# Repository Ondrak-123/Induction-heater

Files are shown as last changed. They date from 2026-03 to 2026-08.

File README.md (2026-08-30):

Macondo link: https://macondo.hackclub.com/projects/6495
# Induction heater
- **This project is an Induction heater based on oscillation (ZVS-Zero Voltage Switching).**
- **The journal can be found at https://stasis.hackclub.com/dashboard/projects/cmmuu5lqf00kx01ns6pu1y2ej (project was started on Statis and now will be finished on Macondo!**
- **The journal features all guides, progress, explanations on how ZVS works and why it is the best way.**
  
**Why am I using softswitching and what is it?**

- Soft switch makes sure that the circuit is not powered instantly but after some time, when connecting an aligator clip or other power source you connect and disconnect the power supply multiple times which can fry the mosfets.

**Why is it called "Zero Voltage Switching"?**

- If one side of the circuit reaches zero volts, it triggers one MOSFET to turn on, while the other stays off and this cycle continues on and on.

**Why is it so efficient?**

- It is efficient thanks to the zero voltage switching, as you can probably tell by the name the mosfets switch at zero volts, thanks to this there is not as much heat generated.

_**Pictures:**_















Created a completely new BOM!:

| I will be using a seller based in the EU. (TME.EU). to avoid new tariff for the EU. I also included AliExpress link so everyone can do this project. I will have 2 orders one from JLCPCB that costs 8.44$. second one from TME.EU. all costs calculated in the total. |  |  |  |  |  |  |  |  |  |  |  |  |  |  |  |  |  |  |  |  |  |
| --- | --- | --- | --- | --- | --- | --- | --- | --- | --- | --- | --- | --- | --- | --- | --- | --- | --- | --- | --- | --- | --- |
| Name | Symbol/TME Code: | Purpose | Link: | Quantity needed: | Total Cost (CZK): | Total cost (USD): |  |  |  |  | Link | Distributor |  |  |  |  |  |  |  |  |  |
| PCB |  | From JLCPCB | * | 1 | *0* | $8.44 |  |  |  |  | https://jlcpcb.com/ | JLCPCB |  |  |  |  |  |  |  |  |  |
| IN4007 Diode |  | For soft starter. | * | 1 | *0* | *0* |  |  |  |  | https://www.aliexpress.com/item/1005010128860199.html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 | Aliexpress |  |  |  |  |  |  |  |  |  |
| Resistor 100KR |  | For soft starter. | * | 1 | *0* | *0* |  |  |  |  | https://www.aliexpress.com/item/1005007539842999.html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 | Aliexpress |  |  |  |  |  |  |  |  |  |
| Power cable |  | For power. HIGH AWG. | * | 1 | *0* | *0* |  |  |  |  | https://www.aliexpress.com/item/1005005203646529.html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 | Aliexpress |  |  |  |  |  |  |  |  |  |
| Freewheeling diode SB1100 | SB1100-DIO | 100V 1A | https://www.tme.eu/cz/details/sb1100-dio/diody-schottky-tht/diotec-semiconductor/sb1100/ | 2 | 7.020 | *0* |  |  |  |  | https://www.aliexpress.com/item/1005007349885370.html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 | Aliexpress |  |  |  |  |  |  |  |  |  |
| Resistor 47R 5W | 5W-47R |  | https://www.tme.eu/cz/details/5w-47r/rezistory-tht/royalohm/mor05sj0470afi/ | 1 | 23.86 | *0* |  |  |  |  | https://www.aliexpress.com/item/1005007330288041.html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 | Aliexpress |  |  |  |  |  |  |  |  |  |
| Zener diode 15V 1W | 1N4744ATR |  | https://www.tme.eu/cz/details/1n4744atr/zenerovy-diody-tht/onsemi/ | 2 | 8.480 | *0* |  |  |  |  | https://www.aliexpress.com/item/1005006886308114.html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 | Aliexpress |  |  |  |  |  |  |  |  |  |
| Resistor 150R 5W | AC05-150R-5% |  | https://www.tme.eu/cz/details/ac05-150r-5%25/vykonne-rezistory/vishay/ac05000001500jac00/ | 2 | 43.86 | *0* |  |  |  |  | https://www.aliexpress.com/item/1005003645133625.html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 | Aliexpress |  |  |  |  |  |  |  |  |  |
| Thermal paste | QOLTEC-51630 | Better heat transfer. | https://www.tme.eu/cz/details/qoltec-51630/teplovodni-pasty/qoltec/51630/ | 2 | 45.02 | *0* |  |  |  |  | https://www.aliexpress.com/item/32833422141.html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 | Aliexpress |  |  |  |  |  |  |  |  |  |
| Capacitor 220uF | CE-220/16PHT-Y | For soft starter. MOQ: 20 | https://www.tme.eu/cz/details/ce-220_16pht-y/elektrolyticke-kondenzatory-tht/aishi/ewh1cm221e11ot/ | 1 | 32.74 | *0* |  |  |  |  | https://www.aliexpress.com/item/1005007322240823.html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 | Aliexpress |  |  |  |  |  |  |  |  |  |
| Capacitor 1.5uF/2uF | C4AF9BU4150A1XK | ZVS switching. | https://www.tme.eu/cz/details/c4af9bu4150a1xk/kondenzatory-foliove-tht/kemet/ | 2 | 157.16 | *0* |  |  |  |  | https://www.tme.eu/cz/details/c4af9bu4150a1xk/kondenzatory-foliove-tht/kemet/ | Aliexpress |  |  |  |  |  |  |  |  |  |
| Resistor 10KR 5W | CRL5W-10K | ZVS switching. MOQ: 10 | https://www.tme.eu/cz/details/crl5w-10k/vykonne-rezistory/sr-passives/ | 2 | 28.46 | *0* |  |  |  |  | https://www.aliexpress.com/item/1005006363058219.html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 | Aliexpress |  |  |  |  |  |  |  |  |  |
| Transistor 2N7000 | 2N7000-DIO | For soft starter. | https://www.tme.eu/cz/details/2n7000-dio/tranzistory-s-kanalem-n-tht/diotec-semiconductor/2n7000/ | 3 | 18.13 | *0* |  |  |  |  | https://www.aliexpress.com/item/1005007206189883.html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 | Aliexpress |  |  |  |  |  |  |  |  |  |
| Inductors | DPT220A5 | Inductors 220uH. | https://www.tme.eu/cz/details/dpt220a5/tlumivky/ferrocore/ | 2 | 107.3 | *0* |  |  |  |  | https://www.aliexpress.com/item/1005009049853632.html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 | Aliexpress |  |  |  |  |  |  |  |  |  |
| Heatsink | SK104-38STS | Mosfet Cooling. | https://www.tme.eu/cz/details/sk104-38sts/chladice/fischer-elektronik/ | 2 | 129.23 | *0* |  |  |  |  | https://www.aliexpress.com/item/1005002711238683.html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 | Aliexpress |  |  |  |  |  |  |  |  |  |
| Mosfet IRFB7730 | IRFB7730PBF | ZVS switching. | https://www.tme.eu/cz/details/irfb7730pbf/tranzistory-s-kanalem-n-tht/infineon-technologies/ | 2 | 159.04 | *0* |  |  |  |  | https://www.aliexpress.com/item/1005011844869795.html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 | Aliexpress |  |  |  |  |  |  |  |  |  |
| Coil |  | Few turns of solid copper wire. | * | 1 | *0* | *0* |  |  |  |  |  |  |  |  |  |  |  |  |  |  |  |
| TME Shipping |  |  | * |  | 169.41 | *0* |  |  |  |  |  |  |  |  |  |  |  |  |  |  |  |
|  |  |  |  |  | 929.71 CZK | 8.44USD |  |  |  | I will not be using these links. but I included them so you cam do this project even if you are not in EU. |  |  |  |  |  |  |  |  |  |  |  |
|  |  |  | 929.71CZK = | 44.97 USD |  |  |  |  |  |  |  |  |  |  |  |  |  |  |  |  |  |
|  |  |  |  | ´+8.44 USD |  |  |  |  |  |  |  |  |  |  |  |  |  |  |  |  |  |
|  |  |  | TOTAL: | 53.41 USD |  |  |  |  |  |  |  |  |  |  |  |  |  |  |  |  |  |
|  |  | REQUESTING AMOUNT: |  | 58 USD |  | SCREENSHOTS/CARTS BELOW!! |  |  |  |  |  |  |  |  |  |  |  |  |  |  |  |
|  |  |  |  |  |  | TME.EU |  |  |  |  |  |  |  |  |  |  |  |  |  |  | LCSC.COM |



Snímek obrazovky 2026-08-20 191143
Snímek obrazovky 2026-08-20 190943

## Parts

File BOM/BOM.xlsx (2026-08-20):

I will be using a seller based in the EU, (TME.EU), to avoid new tariff for the EU. I also included AliExpress link so everyone can do this project. I will have 2 orders one from JLCPCB that costs 8,44$, second one from TME.EU, all costs calculated in the total.
Name | Symbol/TME Code: | Purpose | Link: | Quantity needed: | Total Cost (CZK): | Total cost (USD): |  | Link | Distributor
PCB |  | From JLCPCB | * | 1 | *0* | $8.44 |  | https://jlcpcb.com/ | JLCPCB
IN4007 Diode |  | For soft starter. | * | 1 | *0* | *0* |  | https://www.aliexpress.com/item/1005010128860199.html?curPageLogUid=wIl4TFkDRmTA | Aliexpress
Resistor 100KR |  | For soft starter. | * | 1 | *0* | *0* |  | https://www.aliexpress.com/item/1005007539842999.html?curPageLogUid=Yploor7BfNi6 | Aliexpress
Power cable |  | For power, HIGH AWG. | * | 1 | *0* | *0* |  | https://www.aliexpress.com/item/1005005203646529.html?curPageLogUid=I0lyyNmGkllr | Aliexpress
Freewheeling diode SB1100 | SB1100-DIO | 100V 1A | https://www.tme.eu/cz/details/sb1100-dio/diody-schottky-tht/diotec-semiconductor/sb1100/ | 2 | 7.02 Kč | *0* |  | https://www.aliexpress.com/item/1005007349885370.html?curPageLogUid=PDHqQEwCMyGC | Aliexpress
Resistor 47R 5W | 5W-47R |  | https://www.tme.eu/cz/details/5w-47r/rezistory-tht/royalohm/mor05sj0470afi/ | 1 | 23.86 Kč | *0* |  | https://www.aliexpress.com/item/1005007330288041.html?curPageLogUid=U4fOPbpAK6XU | Aliexpress
Zener diode 15V 1W | 1N4744ATR |  | https://www.tme.eu/cz/details/1n4744atr/zenerovy-diody-tht/onsemi/ | 2 | 8.48 Kč | *0* |  | https://www.aliexpress.com/item/1005006886308114.html?curPageLogUid=5Mdrg3XuXAoh | Aliexpress
Resistor 150R 5W | AC05-150R-5% |  | https://www.tme.eu/cz/details/ac05-150r-5%25/vykonne-rezistory/vishay/ac05000001500jac00/ | 2 | 43.86 Kč | *0* |  | https://www.aliexpress.com/item/1005003645133625.html?curPageLogUid=fSkWTN76PRrU | Aliexpress
Thermal paste | QOLTEC-51630 | Better heat transfer. | https://www.tme.eu/cz/details/qoltec-51630/teplovodni-pasty/qoltec/51630/ | 2 | 45.02 Kč | *0* |  | https://www.aliexpress.com/item/32833422141.html?curPageLogUid=HXpijeaxpZ5p | Aliexpress
Capacitor 220uF | CE-220/16PHT-Y | For soft starter. MOQ: 20 | https://www.tme.eu/cz/details/ce-220_16pht-y/elektrolyticke-kondenzatory-tht/aishi/ewh1cm221e11ot/ | 1 | 32.74 Kč | *0* |  | https://www.aliexpress.com/item/1005007322240823.html?curPageLogUid=mx3EbfFRgrpO | Aliexpress
Capacitor 1,5uF/2uF | C4AF9BU4150A1XK | ZVS switching. | https://www.tme.eu/cz/details/c4af9bu4150a1xk/kondenzatory-foliove-tht/kemet/ | 2 | 157.16 Kč | *0* |  | https://www.tme.eu/cz/details/c4af9bu4150a1xk/kondenzatory-foliove-tht/kemet/ | Aliexpress
Resistor 10KR 5W | CRL5W-10K | ZVS switching. MOQ: 10 | https://www.tme.eu/cz/details/crl5w-10k/vykonne-rezistory/sr-passives/ | 2 | 28.46 Kč | *0* |  | https://www.aliexpress.com/item/1005006363058219.html?curPageLogUid=xUFUBN3jZzu6 | Aliexpress
Transistor 2N7000 | 2N7000-DIO | For soft starter. | https://www.tme.eu/cz/details/2n7000-dio/tranzistory-s-kanalem-n-tht/diotec-semiconductor/2n7000/ | 3 | 18.13 Kč | *0* |  | https://www.aliexpress.com/item/1005007206189883.html?curPageLogUid=WkHDqQGZD8lz | Aliexpress
Inductors | DPT220A5 | Inductors 220uH. | https://www.tme.eu/cz/details/dpt220a5/tlumivky/ferrocore/ | 2 | 107.30 Kč | *0* |  | https://www.aliexpress.com/item/1005009049853632.html?curPageLogUid=ZMnsTrP83ZAj | Aliexpress
Heatsink | SK104-38STS | Mosfet Cooling. | https://www.tme.eu/cz/details/sk104-38sts/chladice/fischer-elektronik/ | 2 | 129.23 Kč | *0* |  | https://www.aliexpress.com/item/1005002711238683.html?curPageLogUid=QgMZjcoePbgO | Aliexpress
Mosfet IRFB7730 | IRFB7730PBF | ZVS switching. | https://www.tme.eu/cz/details/irfb7730pbf/tranzistory-s-kanalem-n-tht/infineon-technologies/ | 2 | 159.04 Kč | *0* |  | https://www.aliexpress.com/item/1005011844869795.html?curPageLogUid=CfFBsAtcuWCR | Aliexpress
Coil |  | Few turns of solid copper wire. | * | 1 | *0* | *0*
TME Shipping |  |  | * |  | 169.41 Kč | *0*
 |  |  |  |  | 929.71 Kč | $8.44 | I will not be using these links, but I included them so you cam do this project even if you are not in EU.
 |  |  | 929,71CZK = | 44,97 USD
 |  |  |  | ´+8,44 USD
 |  |  | TOTAL: | 53,41 USD
 |  | REQUESTING AMOUNT: |  | 58 USD |  | SCREENSHOTS/CARTS BELOW!!
 |  |  |  |  |  | TME.EU |  |  |  | LCSC.COM

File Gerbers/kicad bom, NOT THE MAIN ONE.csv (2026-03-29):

Designator | Footprint | Quantity | Value | LCSC Part #
10UH | PinHeader_1x02_P2.54mm_Vertical | 1 | L
C1, C2, C3, C4, C5 | C_Rect_L33.0mm_W20.0mm_P27.50mm_MKS4 | 5 | 2uF
C6 | CP_Radial_D8.0mm_P3.80mm | 1 | 10uF
C7 | CP_Radial_D8.0mm_P3.80mm | 1 | 220uF
D1, D3 | D_DO-41_SOD81_P12.70mm_Horizontal | 2 | 11DQ10
D2 | D_DO-41_SOD81_P12.70mm_Horizontal | 1 | D_Zener
D4 | D_DO-41_SOD81_P12.70mm_Horizontal | 1 | 15V, 0,5W
D5 | D_DO-41_SOD81_P10.16mm_Horizontal | 1 | 1N4007
HS1, HS2 | Heatsink_AAVID_Extruded_531002B02100G_34.9x12.7mm_H25.4mm | 2 | Heatsink_AAVID_Extruded_531002B02100G_34.9x12.7mm_H25.4mm
J1 | SolderWire-6sqmm_1x02_P14mm_D3.5mm_OD7mm | 1 | PWR_IN
L1, L2 | L_Toroid_Vertical_L21.6mm_W8.4mm_P8.38mm_Pulse_G | 2 | 200uH
Q1, Q2 | TO-220-3_Vertical | 2 | NMOS
Q3, Q4, Q5 | TO-92_Inline | 3 | 2N7000
R1, R2, R7 | R_Axial_DIN0309_L9.0mm_D3.2mm_P12.70mm_Horizontal | 3 | 10kR
R3, R4 | R_Axial_DIN0918_L18.0mm_D9.0mm_P22.86mm_Horizontal | 2 | 150R
R5 | R_Axial_DIN0309_L9.0mm_D3.2mm_P12.70mm_Horizontal | 1 | 47R
R6 | R_Axial_DIN0309_L9.0mm_D3.2mm_P12.70mm_Horizontal | 1 | 100kR

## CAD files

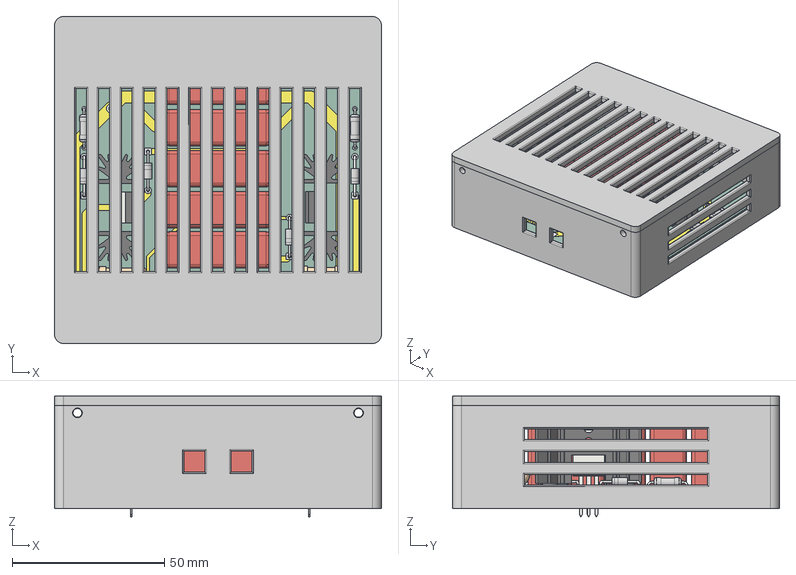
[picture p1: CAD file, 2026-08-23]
Case, Fusion Files/Induction Heater Whole Assembly STEP.step
107.5 x 107.5 x 39.7 mm
Heatsink_AAVID_Extruded_531002B02100G_34.9x12.7mm_H25.4mm x 2
TO-220-3_Vertical x 2
CP_Radial_D8.0mm_P3.80mm x 2
R_Axial_DIN0309_L9.0mm_D3.2mm_P12.70mm_Horizontal x 5
TO-92_Inline x 3
D_DO-41_SOD81_P10.16mm_Horizontal
D_DO-41_SOD81_P12.70mm_Horizontal x 4
C_Rect_L33.0mm_W20.0mm_P27.50mm_MKS4 x 5
R_Axial_DIN0918_L18.0mm_D9.0mm_P22.86mm_Horizontal x 2
Induction heater_copper
Induction heater_pad
Induction heater_via
Induction heater_PCB

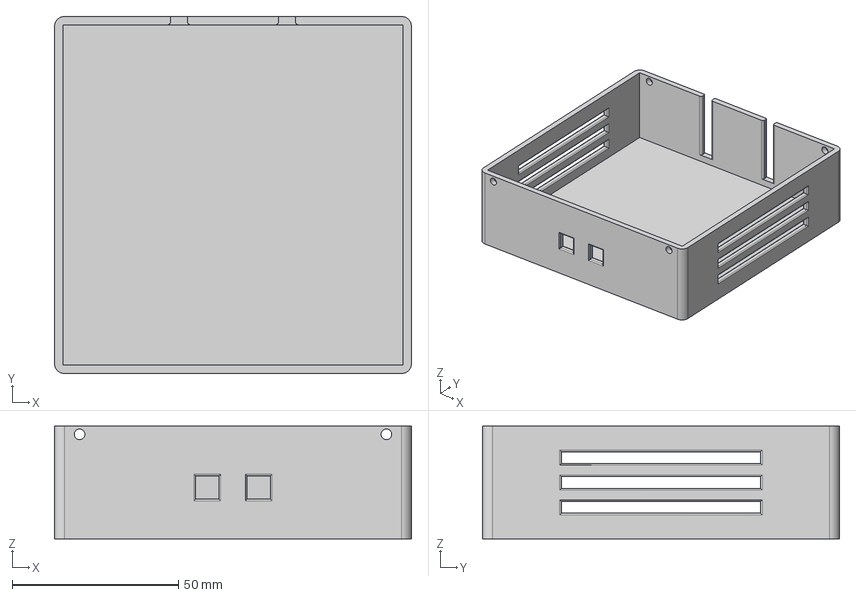
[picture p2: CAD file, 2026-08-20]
Case, Fusion Files/Induction Heater Botom STEP.step
107.5 x 107.5 x 34.0 mm

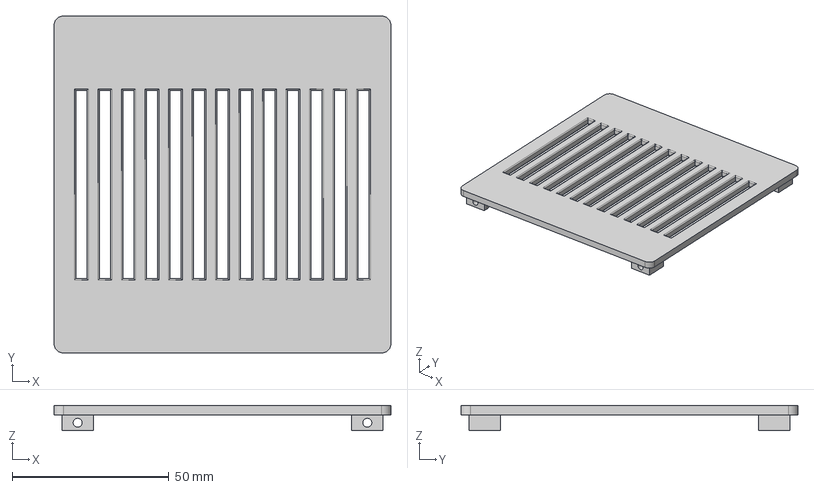
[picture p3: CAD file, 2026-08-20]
Case, Fusion Files/Induction Heater TOP STEP.step
107.5 x 107.5 x 8.00 mm

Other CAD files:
Case, Fusion Files/Induction Heater assembly.f3d

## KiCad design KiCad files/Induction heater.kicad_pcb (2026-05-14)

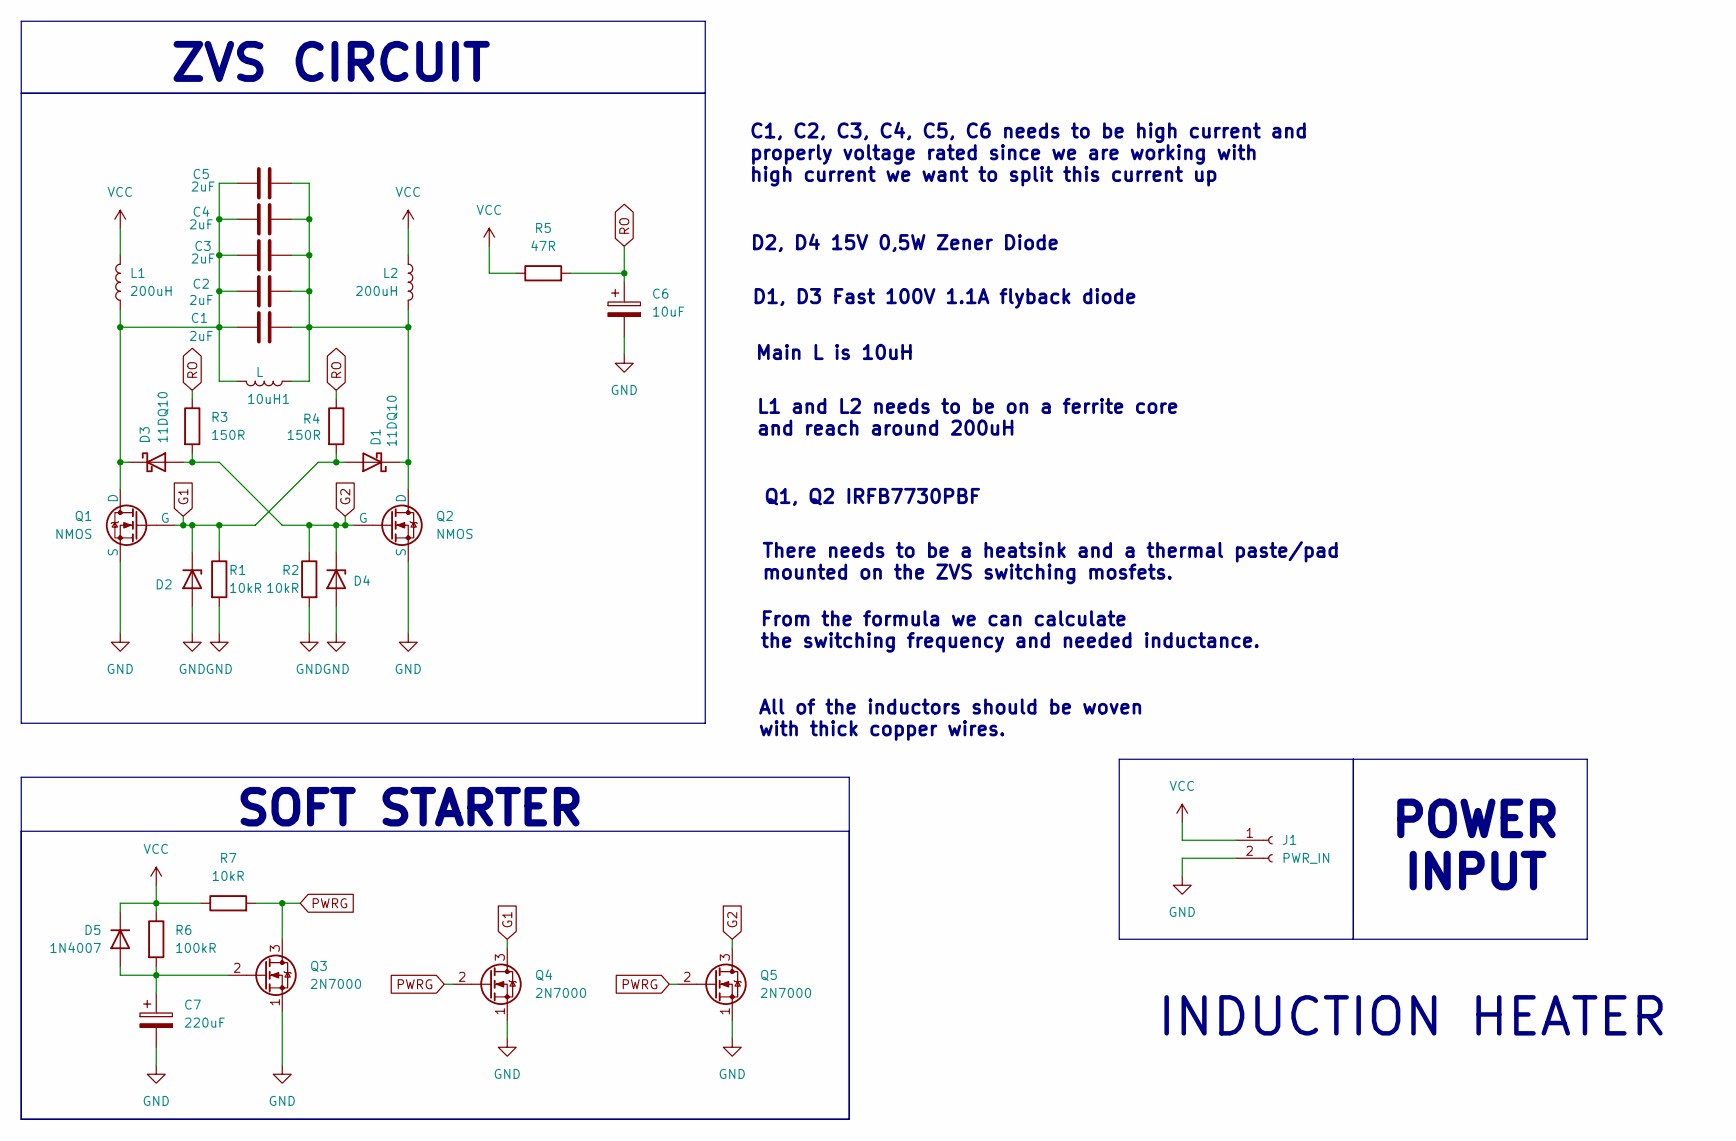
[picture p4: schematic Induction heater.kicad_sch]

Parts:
10uH1: L; PinHeader_1x02_P2.54mm_Vertical
C1, C2, C3, C4, C5: 2uF; C_Rect_L33.0mm_W20.0mm_P27.50mm_MKS4
C6: 10uF; CP_Radial_D8.0mm_P3.80mm
C7: 220uF; CP_Radial_D8.0mm_P3.80mm
D1, D3: 11DQ10; D_DO-41_SOD81_P12.70mm_Horizontal
D2: D_Zener; D_DO-41_SOD81_P12.70mm_Horizontal
D4: 15V, 0,5W; D_DO-41_SOD81_P12.70mm_Horizontal
D5: 1N4007; D_DO-41_SOD81_P10.16mm_Horizontal
J1: PWR_IN; SolderWire-6sqmm_1x02_P14mm_D3.5mm_OD7mm
L1, L2: 200uH; L_Toroid_Vertical_L21.6mm_W8.4mm_P8.38mm_Pulse_G
Q1, Q2: NMOS; TO-220-3_Vertical
Q3, Q4, Q5: 2N7000; TO-92_Inline
R1, R2, R7: 10kR; R_Axial_DIN0309_L9.0mm_D3.2mm_P12.70mm_Horizontal
R3, R4: 150R; R_Axial_DIN0309_L9.0mm_D3.2mm_P12.70mm_Horizontal
R5: 47R; R_Axial_DIN0309_L9.0mm_D3.2mm_P12.70mm_Horizontal
R6: 100kR; R_Axial_DIN0309_L9.0mm_D3.2mm_P12.70mm_Horizontal

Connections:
G1: D1.2 (A), D2.1 (K), Q1.2 (G), Q4.3 (D), R1.1, R4.2
G2: D3.2 (A), D4.1 (K), Q2.2 (G), Q5.3 (D), R2.1, R3.2
GND: C6.2, C7.2, D2.2 (A), D4.2 (A), J1.2, Q1.3 (S), Q2.3 (S), Q3.1 (S), Q4.1 (S), Q5.1 (S), R1.2, R2.2
unnamed 3: 10uH1.2, C1.2, C2.2, C3.2, C4.2, C5.2, D1.1 (K), L2.1, Q2.1 (D); also elsewhere on the board
unnamed 4: 10uH1.1, C1.1, C2.1, C3.1, C4.1, C5.1, D3.1 (K), L1.1, Q1.1 (D); also elsewhere on the board
unnamed: C7.1, D5.2 (A), Q3.2 (G), R6.2
PWRG: Q3.3 (D), Q4.2 (G), Q5.2 (G), R7.2
RO: C6.1, R3.1, R4.1, R5.2
VCC: D5.1 (K), J1.1, L1.2, L2.2, R5.1, R6.1, R7.1

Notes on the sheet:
C1, C2, C3, C4, C5, C6 needs to be high current and properly voltage rated since we are working with high current we want to split this current up
There needs to be a heatsink and a thermal paste/pad mounted on the ZVS switching mosfets.
ZVS CIRCUIT
L1 and L2 needs to be on a ferrite core and reach around 200uH
INDUCTION HEATER
D2, D4 15V 0,5W Zener Diode
Main L is 10uH
From the formula we can calculate the switching frequency and needed inductance.
SOFT STARTER
All of the inductors should be woven with thick copper wires.
POWER INPUT
D1, D3 Fast 100V 1.1A flyback diode
Q1, Q2 IRFB7730PBF

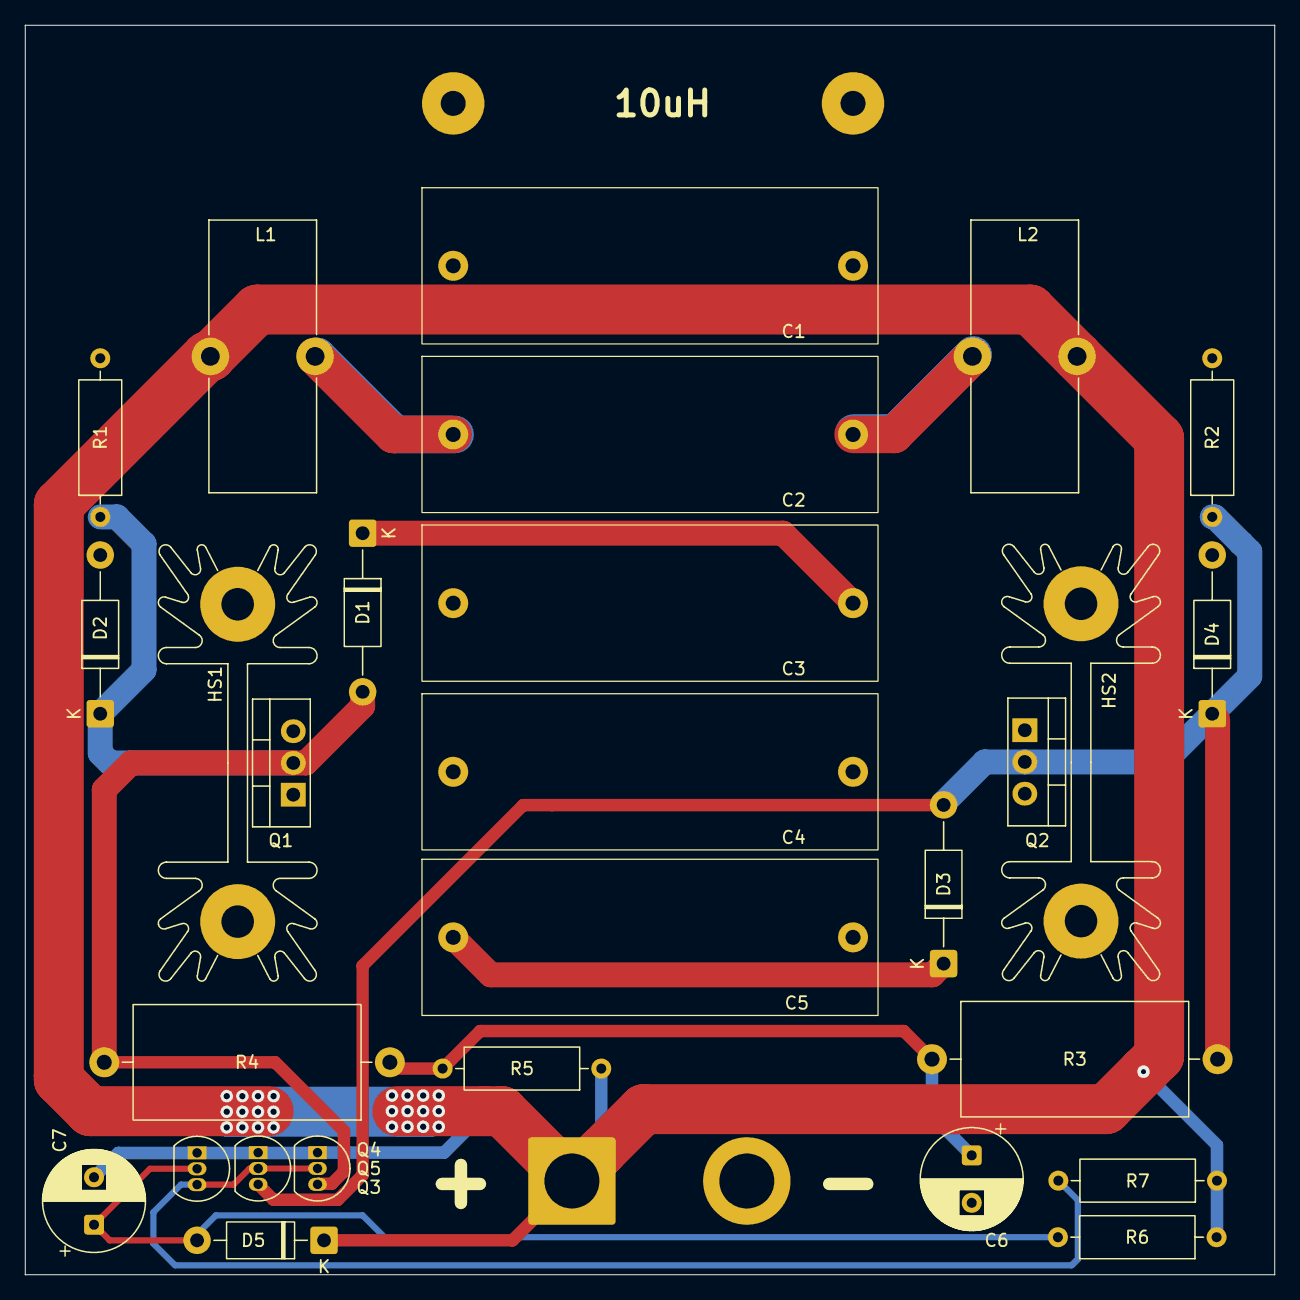
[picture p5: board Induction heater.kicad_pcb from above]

Board: 2 copper layers, 100.0 x 100.0 mm, 30 parts (0 on the bottom side), 9 nets.

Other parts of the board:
10uH: L; PinHeader_1x02_P2.54mm_Vertical
HS1, HS2: Heatsink_AAVID_Extruded_531002B02100G_34.9x12.7mm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; Heatsink_AAVID_Extruded_531002B02100G_34.9x12.7mm_H25.4mm

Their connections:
unnamed 3: 10uH.1; also elsewhere on the board
unnamed 4: 10uH.1; also elsewhere on the board

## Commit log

2026-03-29 BOM change
    [Induction heater-bom.xlsx]
2026-08-23 ADDED CSV
    Please use mainly .XLSX because it is better.
    [BOM CSV.csv]
2026-08-23 Added schematics screenshot
2026-08-23 ADDED CSV
    [BOM CSV.csv, SIMPLIFIED BOM CSV.csv]
2026-08-23 ADDED WHOLE ASSEMBLY IMAGE
2026-08-23 ADDED WHOLE ASSEMBLY IN STEP
    [Induction Heater Whole Assembly STEP.step]
2026-08-26 Updated Image BOM
2026-08-30 Added CSV BOM to /BOM instead of main
    [BOM CSV.csv]
